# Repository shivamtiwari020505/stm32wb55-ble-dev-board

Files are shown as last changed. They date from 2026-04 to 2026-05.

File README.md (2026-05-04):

# stm32wb55-ble-dev-board

> A compact, 4-layer prototype Input/Output board built around the **STM32WB55CEU6** — a dual-core ARM wireless SoC with Bluetooth 5.0 and IEEE 802.15.4 support.

---

## 📌 Overview

The **stm32wb55-ble-dev-board** is a feature-rich embedded development platform designed for IoT, wireless sensing, and industrial control applications. It integrates a high-performance wireless microcontroller with USB-C connectivity, RS232 PC interfacing, RF front-end matching, and a comprehensive set of expansion headers — all on a compact, professional-grade 4-layer red PCB.

---

## 🖼️ Board Preview

| PCB Layout | Circuit Schematic |
|:---:|:---:|
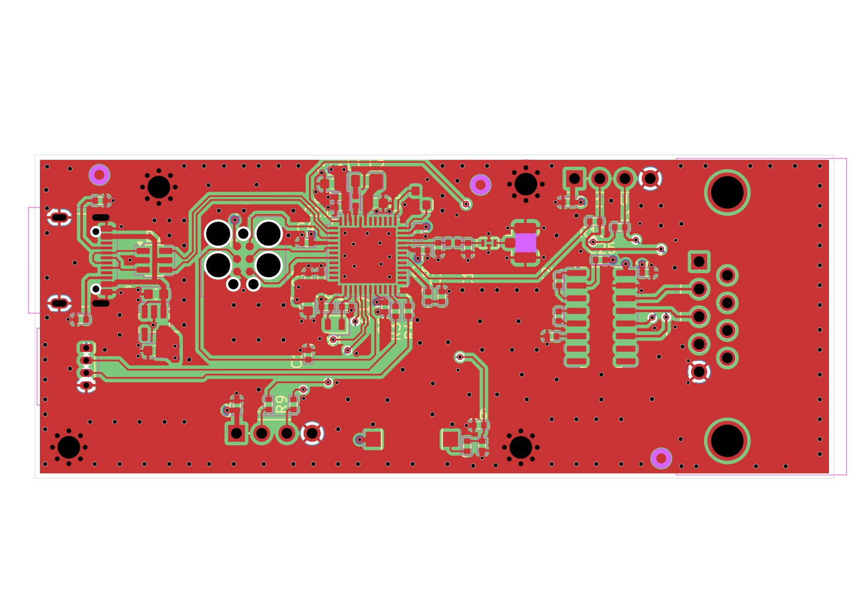
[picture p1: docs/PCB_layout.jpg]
PCB Layout
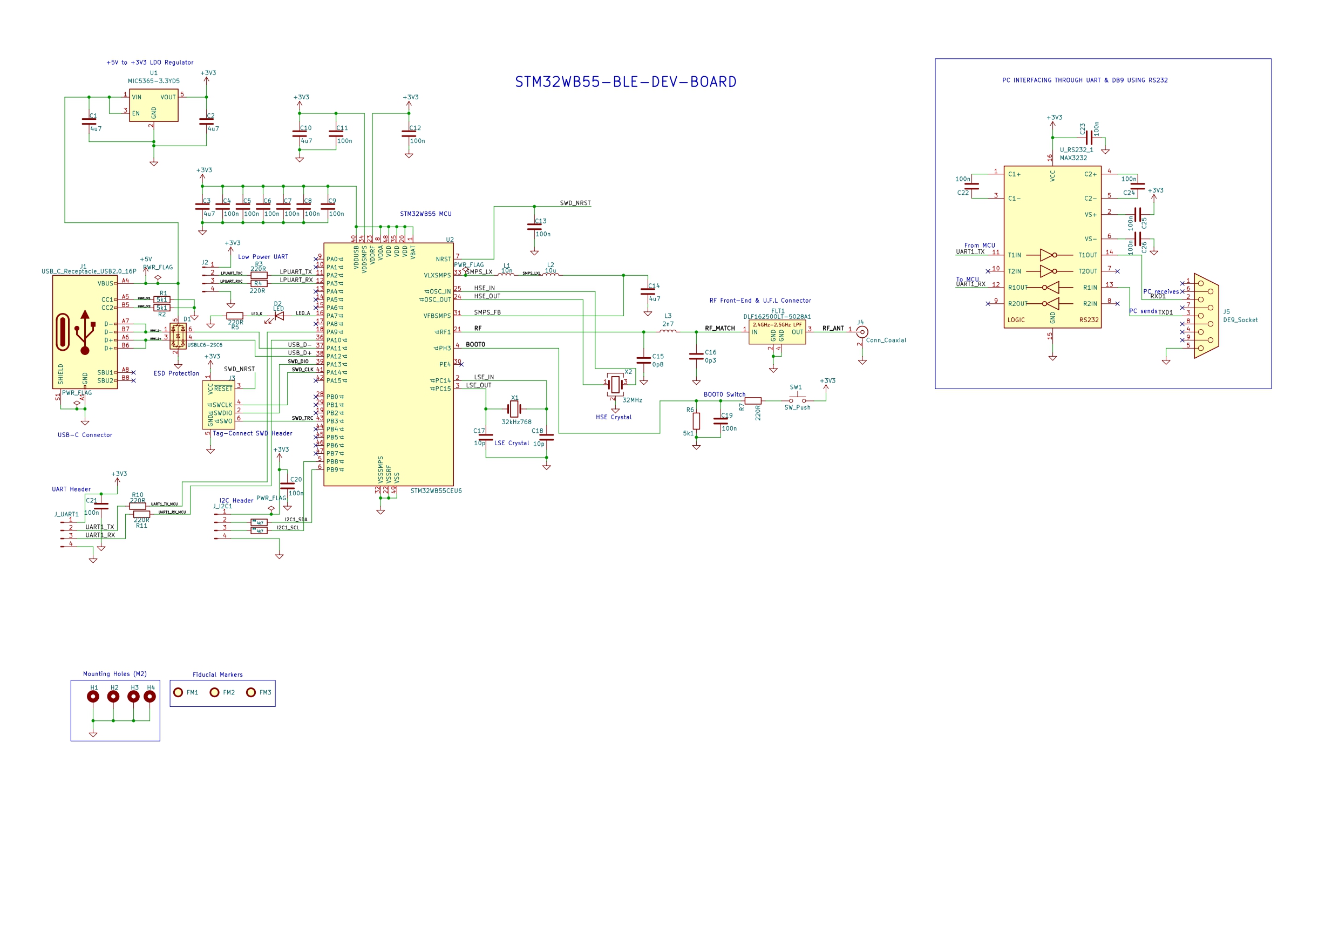
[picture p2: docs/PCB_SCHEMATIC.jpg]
Schematic
|  |  

---

## ✨ Features

- **Dual-Core Wireless MCU** — STM32WB55CEU6 (ARM Cortex-M4 @ 64 MHz + ARM Cortex-M0+ radio core)
- **Bluetooth 5.0 / IEEE 802.15.4** — Zigbee, Thread, OpenThread ready
- **2.4 GHz RF Front-End** — Discrete LC matching network + U.F.L. coaxial antenna connector
- **USB-C Interface** — USB 2.0 Full Speed with ESD protection (USBLC6-2SC6)
- **RS232 PC Interface** — MAX3232 level converter + DB9 connector for legacy serial port compatibility
- **Clean Power Architecture** — MIC5365-3.3YD5 LDO (+5V → +3.3V) with distributed decoupling
- **SWD Debug Interface** — Tag-Connect header (SWDIO, SWDCLK, SWO, NRST)
- **DFU Bootloader** — BOOT0 push-button for USB firmware flashing
- **Expansion Headers** — UART, LPUART, I2C
- **Dual Crystal Oscillators** — 32 MHz HSE (RF) + 32.768 kHz LSE (RTC)
- **4-Layer Red PCB** — M3 mounting holes × 4, Fiducial markers × 3

---

## 🔧 Hardware Specifications

| Parameter | Specification |
|---|---|
| Microcontroller | STM32WB55CEU6 (Cortex-M4 @ 64 MHz + Cortex-M0+) |
| Flash / SRAM | 512 KB Flash / 256 KB SRAM |
| Wireless Protocol | Bluetooth 5.0, IEEE 802.15.4 (Zigbee, Thread) |
| RF Frequency | 2.400 – 2.500 GHz |
| RF Connector | U.F.L. Coaxial |
| Power Input | +5V via USB-C or external header |
| Operating Voltage | +3.3V (MIC5365-3.3YD5 LDO) |
| USB Interface | USB-C 2.0 Full Speed + ESD (USBLC6-2SC6) |
| Serial Interfaces | UART, LPUART, I2C, SWD, RS232 (MAX3232) |
| PC Serial Port | DB9 connector (RS232 ±12V) |
| Debug Interface | SWD Tag-Connect + NRST |
| HSE Crystal | 32 MHz |
| LSE Crystal | 32.768 kHz |
| Boot Mode | BOOT0 push-button switch |
| Mounting Holes | M3 × 4 (H1–H4) |
| Fiducial Markers | FM1, FM2, FM3 |
| PCB | Red, 4-Layer |
| Form Factor | ~80 mm × 35 mm |

---

## 📁 Repository Structure

```
stm32wb55-ble-dev-board/
├── Manufacturing/                          # Gerber files & fabrication outputs
├── Version1_IO_PCBFootprints.pretty/       # Custom KiCad footprint library
├── stm32wb55-ble-dev-board.kicad_pcb       # PCB layout file
├── stm32wb55-ble-dev-board.kicad_sch       # Schematic file
├── stm32wb55-ble-dev-board.kicad_pro       # KiCad project file
├── stm32wb55-ble-dev-board.kicad_prl       # PCB local settings
├── Version1_IO_SchematicSymbol.kicad_sym   # Custom schematic symbol library
├── 530480410.stp                           # 3D model (STEP)
├── DLF162500LT-5028A1--3DModel-STEP.step   # 3D model — RF filter
├── QFN127P600-8N.step                      # 3D model — QFN package
├── fp-lib-table                            # KiCad footprint library table
├── sym-lib-table                           # KiCad symbol library table
├── docs/
│   ├── pcb_layout.jpg                      # PCB layout image
│   └── schematic.jpg                       # Schematic image
└── README.md
```

---

## 🚀 Getting Started

### Prerequisites

- [STM32CubeIDE](https://www.st.com/en/development-tools/stm32cubeide.html) or [STM32CubeWB](https://www.st.com/en/embedded-software/stm32cubewb.html)
- [STM32CubeProgrammer](https://www.st.com/en/development-tools/stm32cubeprog.html) for flashing
- Tag-Connect TC2050 cable for SWD debug
- USB-C cable for power and USB DFU flashing

### Flashing via SWD

1. Connect a Tag-Connect TC2050 cable to the SWD header on the board.
2. Open STM32CubeIDE or STM32CubeProgrammer.
3. Select **STM32WB55CEU6** as the target device.
4. Flash your `.elf` or `.hex` firmware file.

### Flashing via USB DFU (Bootloader)

1. Hold the **BOOT0** button while powering the board via USB-C.
2. The MCU will enumerate as a DFU device on your PC.
3. Use STM32CubeProgrammer or `dfu-util` to flash:

```bash
dfu-util -a 0 -s 0x08000000:leave -D firmware.bin
```

### RS232 / PC Serial Interface

Connect a DB9 serial cable between the board and your PC (or use a USB-to-RS232 adapter). The MAX3232 handles level conversion automatically. Default UART settings:

```
Baud Rate : 115200
Data Bits : 8
Parity    : None
Stop Bits : 1
Flow Ctrl : None
```

---

## 📡 RF & Antenna

The RF front-end uses a discrete LC matching network and low-pass filter (DLC1625D-S0Z8A5) tuned for the 2.4–2.5 GHz band, feeding into a **U.F.L. coaxial connector**. Connect an external 2.4 GHz antenna (via U.F.L. or SMA adapter) before powering the RF subsystem.

> ⚠️ **Do not operate the RF transmitter without an antenna connected.** This may damage the RF front-end.

---

## 🔌 Pinout & Connectors

| Connector / Header | Signal(s) | Description |
|---|---|---|
| USB-C (J1) | VBUS, D+, D−, CC1, CC2 | USB 2.0 Full Speed + Power |
| SWD Tag-Connect | SWDIO, SWDCLK, SWO, NRST, GND, 3V3 | Debug & Programming |
| UART Header | UART_TX, UART_RX, GND | General-purpose UART |
| LPUART Header | LPUART_TX, LPUART_RX, GND | Low-power UART |
| I2C Header | I2C_SCL, I2C_SDA, GND, 3V3 | I2C expansion |
| DB9 (J5) | RS232 TX, RX | PC serial port |
| RF (J1) | RF_ANT | U.F.L. coaxial antenna |
| BOOT0 (SW1) | BOOT0 | DFU bootloader trigger |

---

## 📐 PCB Stack-up

| Layer | Function |
|---|---|
| L1 (Top) | Signal + Components |
| L2 | Ground Plane |
| L3 | Power Plane (+3.3V) |
| L4 (Bottom) | Signal |

---

## 🤝 Contributing

Pull requests are welcome! For major changes, please open an issue first to discuss what you would like to change.

---

## 📬 Contact

For questions or collaboration, open an issue on this repository.

---

*Designed with STM32WB55CEU6 · 4-Layer PCB · Bluetooth 5.0 · IEEE 802.15.4*

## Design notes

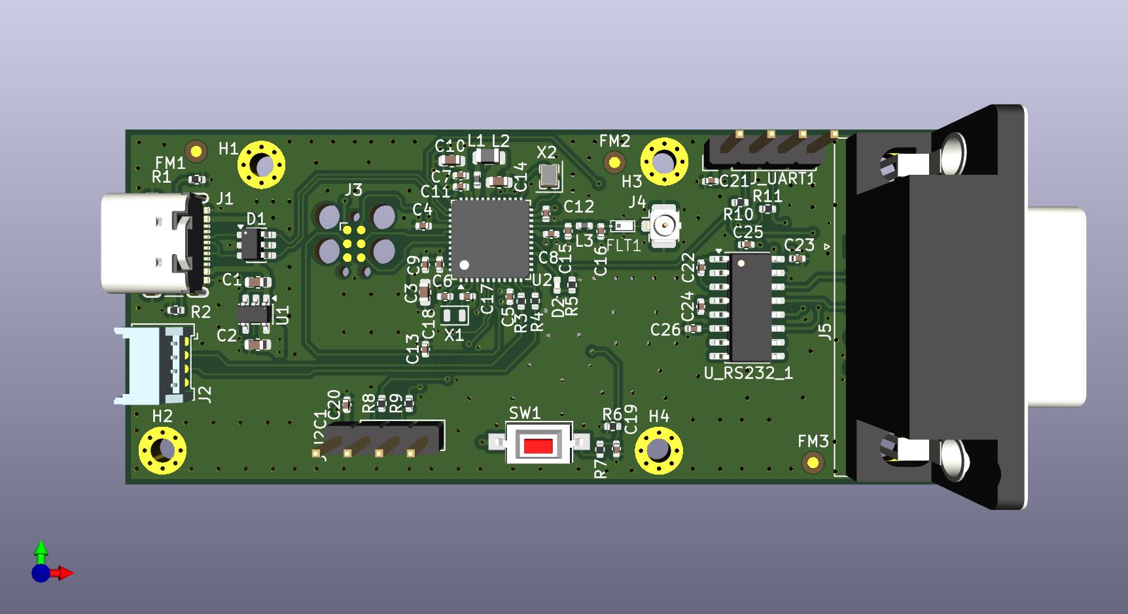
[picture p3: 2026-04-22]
docs/stm32wb55-ble-dev-board_3DView.jpg

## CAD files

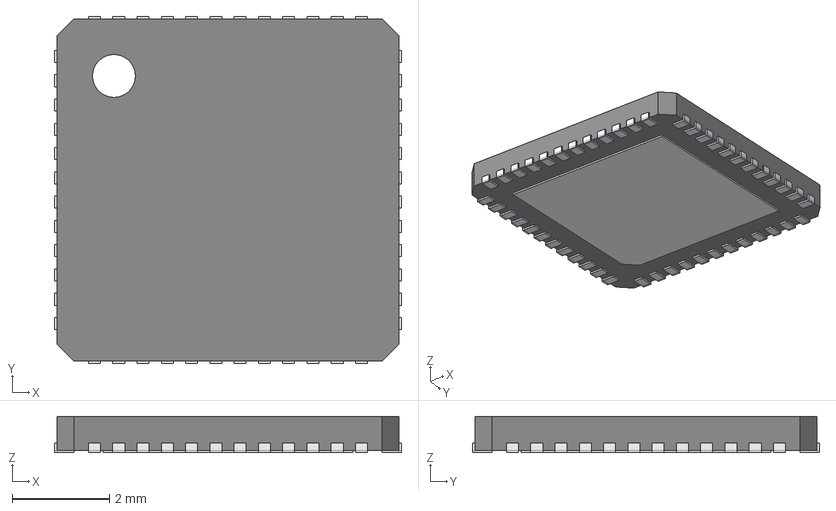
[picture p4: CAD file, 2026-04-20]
QFN127P600-8N.step
7.15 x 7.15 x 0.75 mm
Open_CASCADE_STEP_translator_6.8_1.1
Open_CASCADE_STEP_translator_6.8_1.2.1
Thermal_Shape
Open_CASCADE_STEP_translator_6.8_1.4.1 x 48

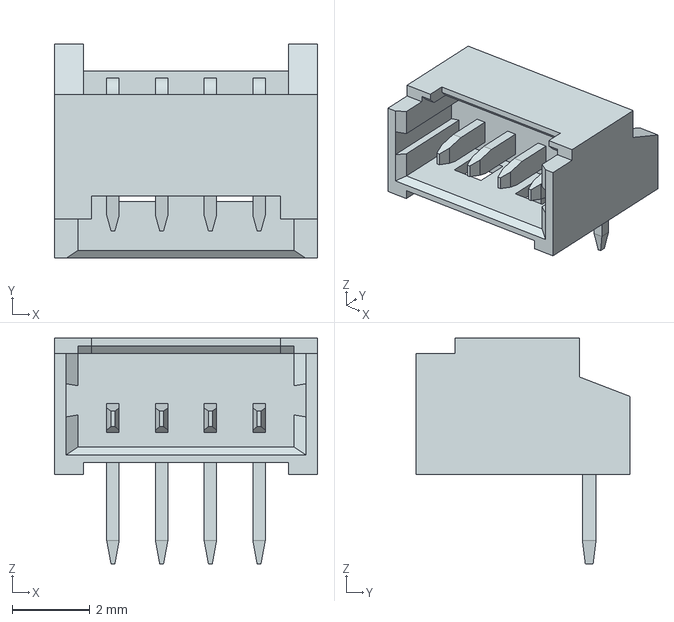
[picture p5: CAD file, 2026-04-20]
530480410.stp
6.75 x 5.50 x 5.80 mm

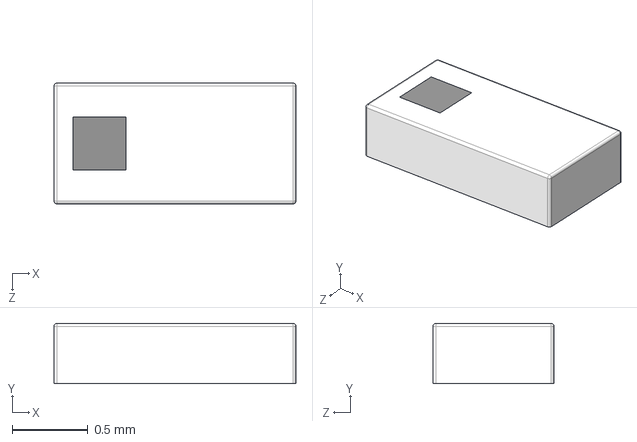
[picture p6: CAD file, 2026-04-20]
DLF162500LT-5028A1--3DModel-STEP-269445.STEP
1.60 x 0.4 x 0.8 mm

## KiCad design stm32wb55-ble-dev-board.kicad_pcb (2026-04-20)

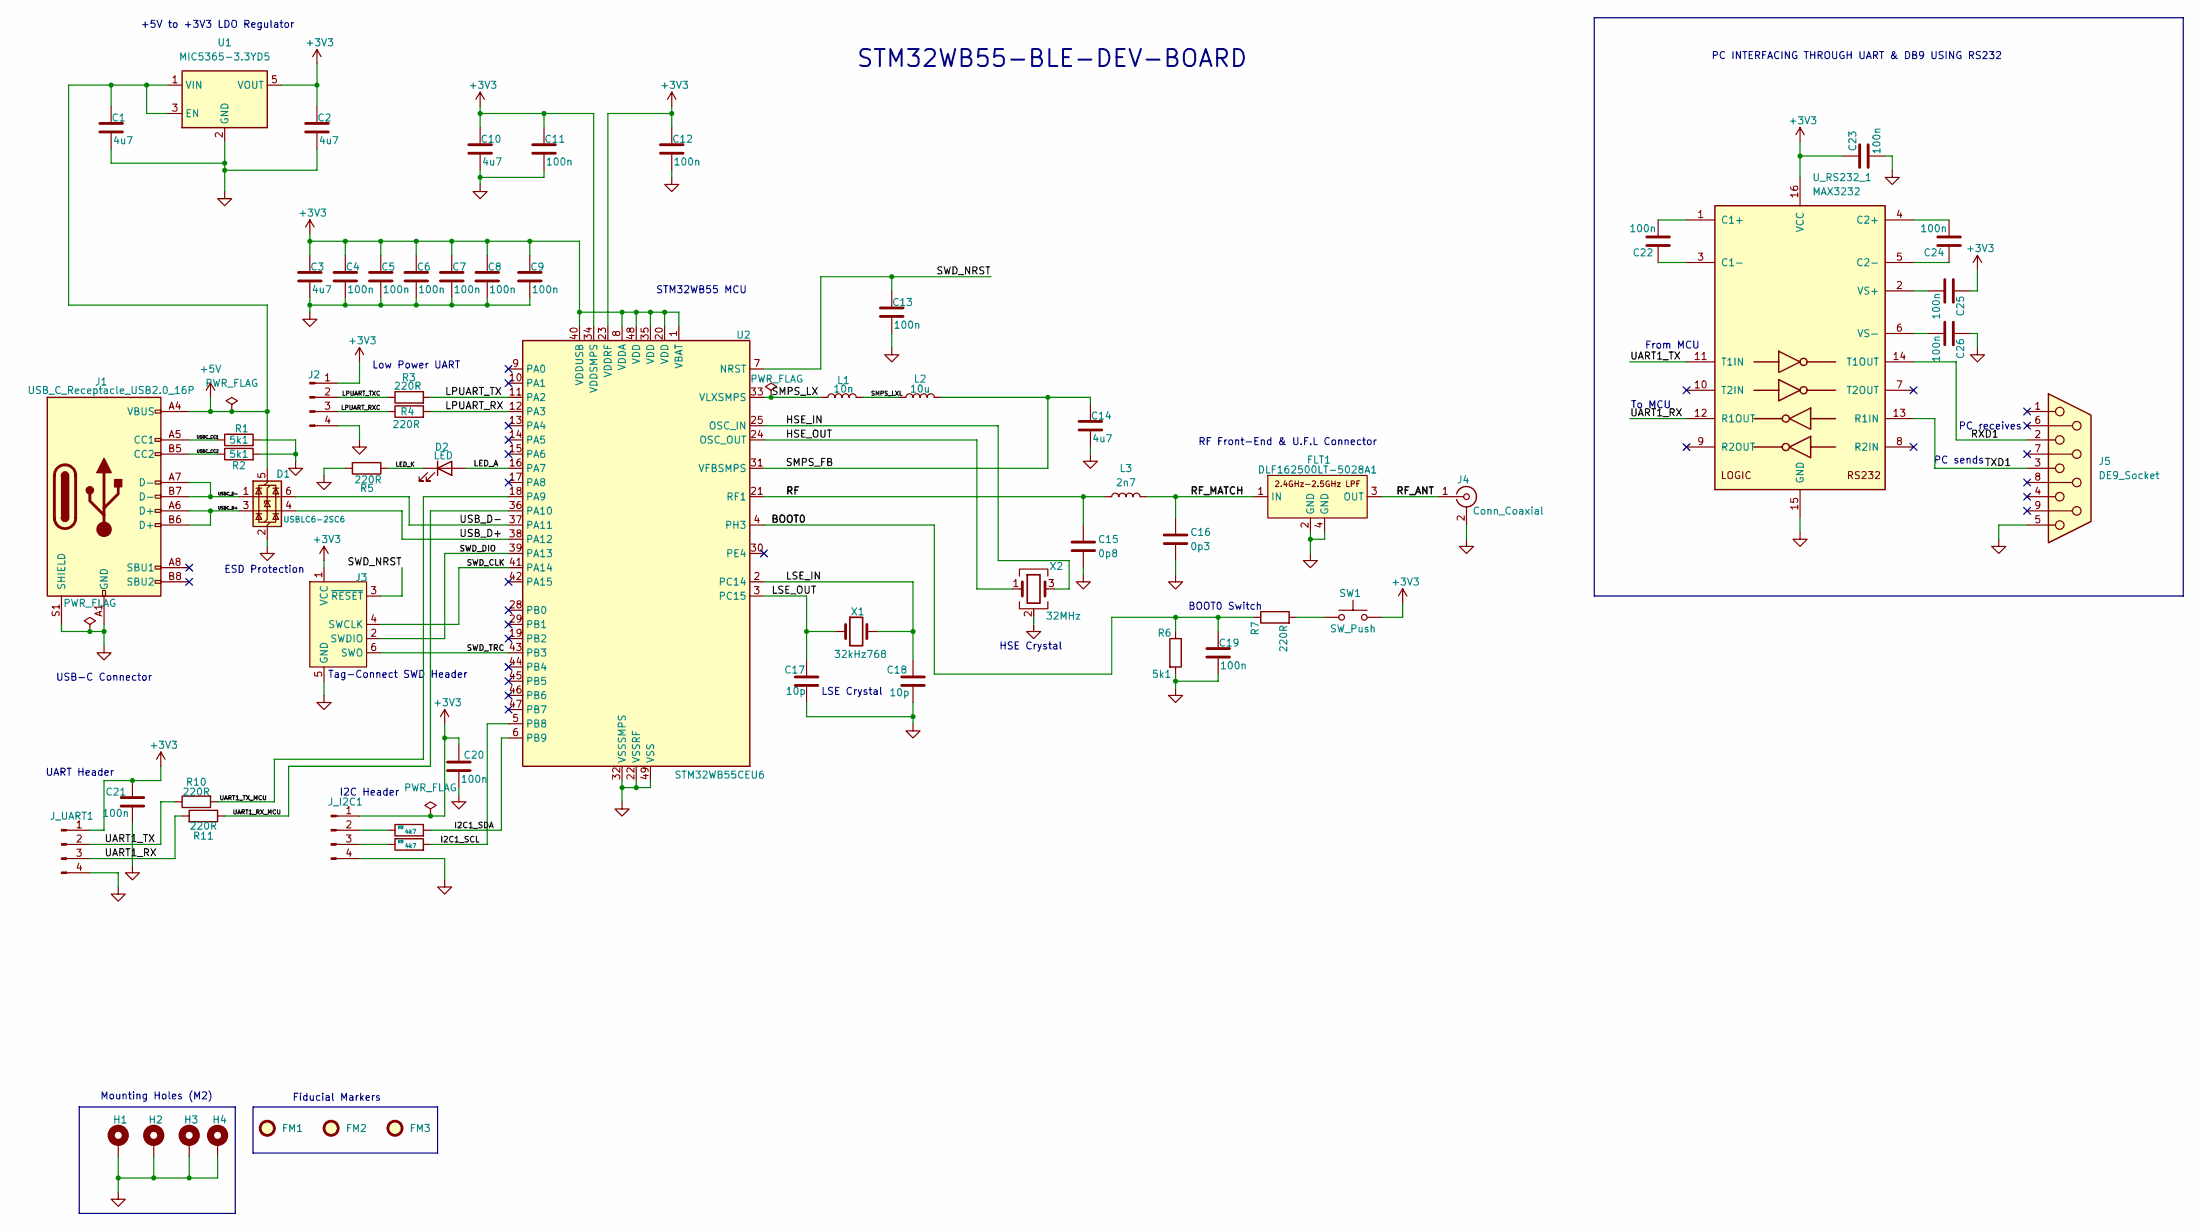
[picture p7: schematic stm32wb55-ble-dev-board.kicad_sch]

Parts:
C1, C2, C3, C10, C14: 4u7; C_0603_1608Metric
C4, C5, C6, C7, C8, C9, C11, C12, C13, C19, C20, C21, C22, C23, C24, C25, C26: 100n; C_0402_1005Metric
C15: 0p8; C_0402_1005Metric
C16: 0p3; C_0402_1005Metric
C17, C18: 10p; C_0402_1005Metric
D1: USBLC6-2SC6; SOT-23-6
D2: LED; LED_0402_1005Metric
FLT1: DLF162500LT-5028A1
FM1, FM2, FM3: Fiducial; Fiducial_1mm_Mask2mm
H1, H2, H3, H4: MountingHole_Pad; MountingHole_2.2mm_M2_Pad_Via
J1: USB_C_Receptacle_USB2.0_16P; USB_C_Receptacle_GCT_USB4105-xx-A_16P_TopMnt_Horizontal
J2: Conn_01x04_Pin; Molex_PicoBlade_53048-0410_1x04_P1.25mm_Horizontal
J3: Conn_ARM_SWD_TagConnect_TC2030; Tag-Connect_TC2030-IDC-FP_2x03_P1.27mm_Vertical
J4: Conn_Coaxial; U.FL_Hirose_U.FL-R-SMT-1_Vertical
J5: DE9_Socket; DSUB-9_Socket_Horizontal_P2.77x2.84mm_EdgePinOffset4.94mm_H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
J_I2C1: Conn_01x04_Pin; PinHeader_1x04_P2.54mm_Vertical
J_UART1: Conn_01x04_Pin; PinHeader_1x04_P2.54mm_Vertical
L1: 10n; L_0402_1005Metric
L2: 10u; L_0805_2012Metric
L3: 2n7; L_0402_1005Metric
R1, R2, R6: 5k1; R_0402_1005Metric
R3, R4, R5, R7, R10, R11: 220R; R_0402_1005Metric
R8, R9: 4k7; R_0402_1005Metric
SW1: SW_Push; SW_SPST_CK_RS282G05A3
U1: MIC5365-3.3YD5; TSOT-23-5
U2: STM32WB55CEU6; QFN-48-1EP_7x7mm_P0.5mm_EP5.6x5.6mm
U_RS232_1: MAX3232; SOIC-16_3.9x9.9mm_P1.27mm
X1: 32kHz768; Crystal_SMD_2012-2Pin_2.0x1.2mm
X2: 32MHz; Crystal_SMD_2016-4Pin_2.0x1.6mm

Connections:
+3V3: C2.1, C3.1, C4.1, C5.1, C6.1, C7.1, C8.1, C9.1, C10.1, C11.1, C12.1, C20.1, C21.1, C23.1, C25.1, J2.1, J3.1 (VCC), J_I2C1.1, J_UART1.1, SW1.2, U1.5 (VOUT), U2.1 (VBAT), U2.8 (VDDA), U2.20 (VDD), U2.23 (VDDRF), U2.34 (VDDSMPS), U2.35 (VDD), U2.40 (VDDUSB), U2.48 (VDD), U_RS232_1.16 (VCC)
+5V: C1.1, D1.5 (VBUS), J1.A4 (VBUS), J1.A9 (VBUS), J1.B4 (VBUS), J1.B9 (VBUS), U1.1 (VIN), U1.3 (EN)
/BOOT0: C19.1, R6.1, R7.1, U2.4 (PH3)
/HSE_IN: U2.25 (OSC_IN), X2.3
/HSE_OUT: U2.24 (OSC_OUT), X2.1
/I2C1_SCL: R9.2, U2.5 (PB8)
/I2C1_SDA: R8.2, U2.6 (PB9)
/LED_A: D2.2 (A), U2.16 (PA7)
/LED_K: D2.1 (K), R5.1
/LPUART_RX: R4.2, U2.12 (PA3)
/LPUART_RXC: J2.3, R4.1
/LPUART_TX: R3.2, U2.11 (PA2)
/LPUART_TXC: J2.2, R3.1
/LSE_IN: C18.1, U2.2 (PC14), X1.2
/LSE_OUT: C17.1, U2.3 (PC15), X1.1
/RF: C15.1, L3.1, U2.21 (RF1)
/RF_ANT: FLT1.3 (OUT), J4.1 (In)
/RF_MATCH: C16.1, FLT1.1 (IN), L3.2
/RXD1: J5.2, U_RS232_1.14 (T1OUT)
/SMPS_FB: C14.1, L2.2, U2.31 (VFBSMPS)
/SMPS_LX: L1.1, U2.33 (VLXSMPS)
/SMPS_LXL: L1.2, L2.1
/SWD_CLK: J3.4 (SWCLK), U2.41 (PA14)
/SWD_DIO: J3.2 (SWDIO), U2.39 (PA13)
/SWD_NRST: C13.1, J3.3 (~RESET), U2.7 (NRST)
/SWD_TRC: J3.6 (SWO), U2.43 (PB3)
/TXD1: J5.3, U_RS232_1.13 (R1IN)
/UART1_RX: J_UART1.3, R11.2, U_RS232_1.12 (R1OUT)
/UART1_RX_MCU: R11.1, U2.36 (PA10)
/UART1_TX: J_UART1.2, R10.1, U_RS232_1.11 (T1IN)
/UART1_TX_MCU: R10.2, U2.18 (PA9)
/USBC_CC1: J1.A5 (CC1), R1.1
/USBC_CC2: J1.B5 (CC2), R2.1
/USBC_D+: D1.3 (I/O2), J1.A6 (D+), J1.B6 (D+)
/USBC_D-: D1.1 (I/O1), J1.A7 (D-), J1.B7 (D-)
/USB_D+: D1.4 (I/O2), U2.38 (PA12)
/USB_D-: D1.6 (I/O1), U2.37 (PA11)
GND: C1.2, C2.2, C3.2, C4.2, C5.2, C6.2, C7.2, C8.2, C9.2, C10.2, C11.2, C12.2, C13.2, C14.2, C15.2, C16.2, C17.2, C18.2, C19.2, C20.2, C21.2, C23.2, C26.1, D1.2 (GND), FLT1.2 (GND), FLT1.4 (GND), H1.1, H2.1, H3.1, H4.1, J1.A1 (GND), J1.A12 (GND), J1.B1 (GND), J1.B12 (GND), J1.S1 (SHIELD), J2.4, J3.5 (GND), J4.2 (Ext), J5.5, J_I2C1.4, J_UART1.4, R1.2, R2.2, R5.2, R6.2, U1.2 (GND), U2.22 (VSSRF), U2.32 (VSSSMPS), U2.49 (VSS), U_RS232_1.15 (GND), X2.2 (G), X2.4 (G)
unnamed: J_I2C1.2, R8.1
unnamed: J_I2C1.3, R9.1
unnamed: R7.2, SW1.1
unnamed: C22.2, U_RS232_1.1 (C1+)
unnamed: C22.1, U_RS232_1.3 (C1-)
unnamed: C24.2, U_RS232_1.4 (C2+)
unnamed: C24.1, U_RS232_1.5 (C2-)
unnamed: C25.2, U_RS232_1.2 (VS+)
unnamed: C26.2, U_RS232_1.6 (VS-)

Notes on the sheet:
STM32WB55 MCU
PC sends
USB-C Connector
From MCU
PC INTERFACING THROUGH UART & DB9 USING RS232
Mounting Holes (M2)
To MCU
ESD Protection
HSE Crystal
LSE Crystal
PC receives
I2C Header
BOOT0 Switch
Low Power UART
Fiducial Markers
UART Header
Tag-Connect SWD Header
RF Front-End & U.F.L Connector
STM32WB55-BLE-DEV-BOARD
+5V to +3V3 LDO Regulator

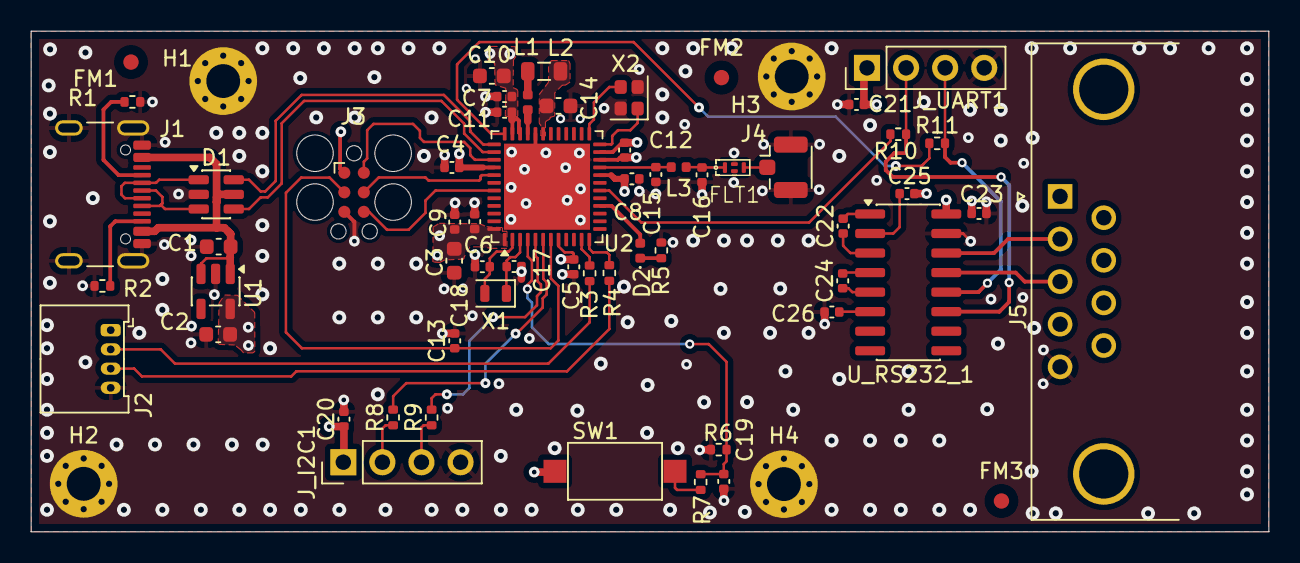
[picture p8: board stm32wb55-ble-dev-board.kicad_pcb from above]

Board: 4 copper layers, 80.5 x 32.5 mm, 63 parts (0 on the bottom side), 47 nets.

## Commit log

2026-04-20 Add files via upload
    Initial commit: Added custom STM32WB55 schematic, PCB layout, 3D models, and manufacturing gerbers
    [530480410.stp, DLF162500LT-5028A1--3DModel-STEP-269445.STEP, QFN127P600-8N.step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]
2026-04-22 Enhance README with detailed board information
    Expanded the README to include detailed features, specifications, and usage instructions for the STM32WB55 development board.
